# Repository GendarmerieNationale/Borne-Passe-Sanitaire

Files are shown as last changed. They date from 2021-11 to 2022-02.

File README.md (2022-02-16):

# BORNE PASSE SANITAIRE - BPS

Elaborée dans le cadre de la crise COVID, la borne permet de scanner soi-même son passe sanitaire et d’en confirmer la validité, via l’application Tous Anti-Covid Vérif, grâce à un signal sonore. Beaucoup moins coûteux que les produits du marché, cette borne évite de dédier une personne au contrôle des passes sanitaires et répond ainsi à un besoin rendu nécessaire par la crise sanitaire.

Conçue initialement pour les besoins internes de la Gendarmerie (cérémonies, salles de sport, accès des personnes extérieures aux mess…) cette innovation peut être utile à de nombreux acteurs publics et privés (petites collectivités, cinémas...). 

Reposant sur une architecture ANDROID, la borne peut accueillir des applications équivalentes à TAC VERIF dans d'autres pays. Elle peut être également utilisée pour d'autres usages tels que billeterie, contrôle d'accès, etc...

Ce dépôt vous permet de construire une borne passe sanitaire.

## LICENCE

CERN Open Hardware Licence Version 2 - Weakly Reciprocal

## DOCUMENTATION

La documentation est disponible dans le dossier /docs
 - BPS Documentation technique FR.pdf

## IMPRESSION 3D DU BOITIER

### Plans 3D

Les fichiers stl sont disponibles dans le dossier /stl
 - BPS_blocbatterie.stl
 - BPS_fixation.stl
 - BPS_gabarit.stl
 - BPS.stl

### Fichiers gcode pour imprimantes

Les fichiers gcode sont disponibles pour les imprimantes
 - TEVY dans le dossier /gcode/tevy
 - TIZYX dans le dossier /gcode/tizyx

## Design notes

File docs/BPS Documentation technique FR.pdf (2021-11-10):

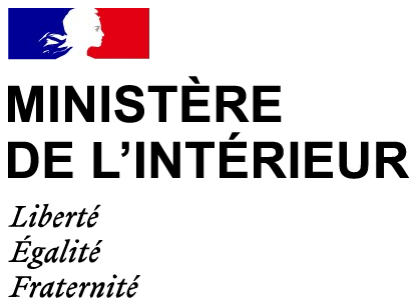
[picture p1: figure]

Gendarmerie nationale

### 20 octobre 2021

N° 67923 GEND/COMSOPGN/SCRTA

D O C U M E N T A T I O N T E C H N I Q U E
B P S – B O R N E P O U R P A S S E S A N I T A I R E

OBJET : Documentation technique de la borne pour passe sanitaire (tutoriel de montage et d’assemblage).

PRESENTATION :
De sa propre initiative, la section CARDIO du SCRTA s’est penchée sur la réalisation d’une borne permettant de vérifier et informer sur la validité d’un passe sanitaire en scannant le QR code depuis la section « carnets » de l’application TousAntiCovid. Le résultat de la validité s’affiche temporairement sur un écran, sans en conserver la donnée.
Ce document a pour objectif de rendre possible la fabrication de la borne « passe sanitaire » par l’ensemble des « makers » gendarmerie.

RÉFÉRENCE(S) :

DESTINATAIRE(S) :
Pour Action :
- DGGN/ST/DPI - Département de la prospective et de l’innovation

A titre de compte rendu :
- COMSOPGN
- SCRTA

Copie :
- Archive CARDIO

Historique des révisions

Numéro de version | Description | Date de modification | Auteur
V1.0 | Création du document | Octobre 2021 | MDC SOPHIE
V1.1 | Modification suite retex terrain DGGN | Octobre 2021 | MDC SOPHIE
V1.2 | Ajout mentions par la DGGN | Octobre 2021 | ST/DPI

A l’exception de l’usage prévu par la notice (et la licence) qui requiert de mentionner la paternité du projet, tous usages de la dénomination « Gendarmerie Nationale » et/ou de son logo institutionnel sont interdits, et ce à quelque titre que ce soit.

Décharge disclaimer
This source is distributed WITHOUT ANY EXPRESS OR IMPLIED WARRANTY, INCLUDING OF MERCHANTABILITY, SATISFACTORY QUALITY AND FITNESS FOR A PARTICULAR PURPOSE. Please see the CERN-OHL-S v2 for applicable conditions.

Conformément à la licence CERN-OHL v2, la mise à disposition de ce document n’implique aucune garantie ni responsabilité pour l’ensemble des usages qui pourraient en être faits.

Ce document est distribué sous la licence CERN Open Hardware Licence Version 2 -Weakly Reciprocal disponible sous le lien ci-contre https://ohwr.org/cern_ohl_w_v2.pdf.

## Table des matières

### 1. PRÉSENTATION DU PRODUIT :

La borne permet de vérifier et informer sur la validité d’un pass sanitaire en scannant le QR code depuis la section « carnets » de l’application TousAntiCovid. Le résultat de la validité s’affiche temporairement sur un écran, sans en conserver la donnée.

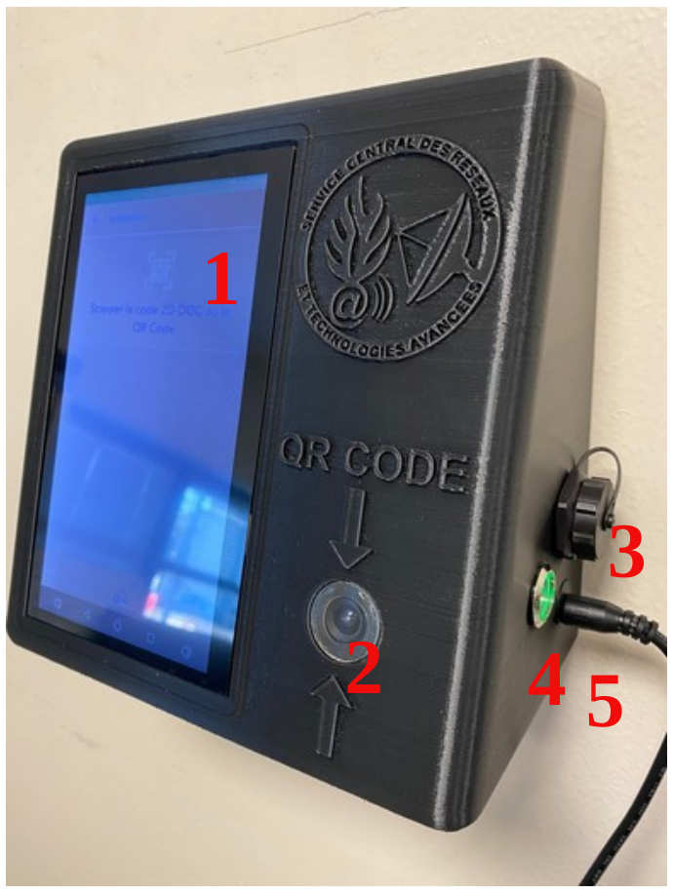
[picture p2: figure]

Le Boîtier est imprimé en 3D (PLA ou ABS). Il est prévu d’être installé au mur à l’aide de trois trous de fixation situés à l’arrière. Un gabarit de perçage est également disponible. Les paramètres d’impression ainsi que l’ensemble des fichiers STL sont disponibles sur le github.

La borne embarque un écran tactile de 7’’ (17cm) monté verticalement afin d’apporter d’avantage d’ergonomie et d’interactivité. (1)
La lecture du QR Code est réalisée par une webcam (2) d’une définition de 1080p, équipée d’une mise au point automatique.
Une fonctionnalité optionnelle est la mise en place d’un système miroir pour faciliter l’ergonomie de la lecture du QR code. Plusieurs solutions techniques sont possibles :
- dispositif électronique sur la caméra et/ou sa connectique ;
- dispositif optique (mise en place d’un miroir à 45°) ;
- dispositif logique (réglage à effectuer sur le pilote de la caméra).
Un port USB (3) est également disponible sur le coté de la borne afin d’y connecter divers périphériques selon le besoin (clavier, souris, clé 4G, etc..). Attention, il n’est pas destiné à la mise en charge (ne pas connecter de source d’alimentation, ex : batterie externe).
La mise en marche/arrêt du système est réalisée à l’aide de l’interrupteur (4) monté sur le coté de la borne (voyant vert → marche).
La mise sous tension secteur est réalisée par un bloc d’alimentation 5V/4A – 5.5x2.5mm - femelle - EU/UK/US (100-240V). Une fiche d’alimentation femelle est également assemblée sur le coté de la borne (5).
L’ensemble des composants électroniques est géré par un micro-ordinateur embarquant un Android 7, 2Go de RAM, et un processeur Quad-Core Rockhip RK3288 (exemple utilisé : ASUS Tinker Board ).

### 2. IMPRESSION 3D DU BOÎTIER :

La borne est conçue et modélisée pour être en majeure partie imprimée en 3D. Elle est décomposée en 4 fichiers STL, ainsi que les fichiers « .gcode » pour imprimante Tizyx EVY, tous disponibles :

Fichiers STL :
Fichiers à ouvrir dans CURA, l’ensemble des paramètres est à renseigner manuellement.
- BPS.stl (fichier principale de la borne).
- BPS_fixation.stl (fichier principale plaque arrière pour fixation).
- BPS_gabarit.stl (fichier optionnel pour faciliter le perçage).
- BPS_blocbatterie.stl (fichier réservé à usage futur pour la fixation d’une batterie).

Fichiers Gcodes (uniquement pour TIZYX EVY) :
Fichier à lancer directement depuis l’imprimante, il contient l’ensemble des paramètres d’impression. Cette opération est recommandée par la section CARDIO.
- TEVY_BPS.gcode
- TEVY_BPS_fixation.gcode (fichier principale plaque arrière
pour fixation).
- TEVY_BPS_gabarit.gcode (fichier optionnel pour faciliter le perçage).
- TEVY_BPS_Blocbatterie.gcode (fichier réservé usage futur pour la fixation d’une batterie).

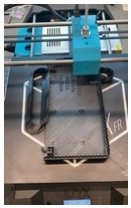
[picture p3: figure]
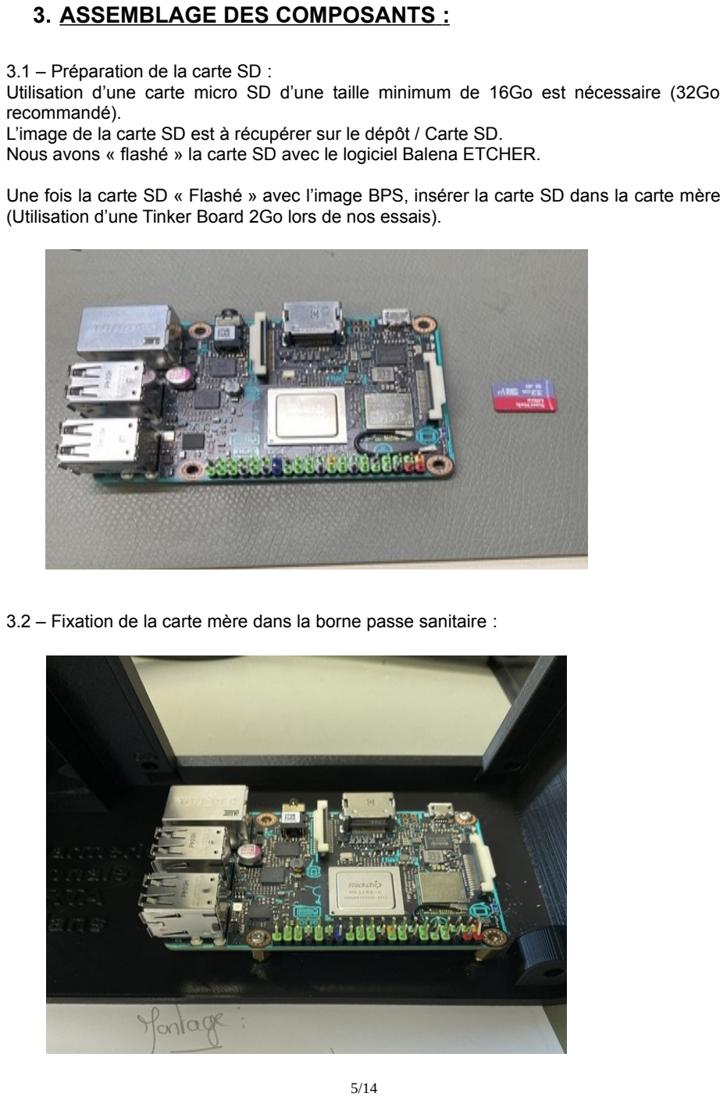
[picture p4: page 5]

### 3. ASSEMBLAGE DES COMPOSANTS :

3.1 – Préparation de la carte SD :
Utilisation d’une carte micro SD d’une taille minimum de 16Go est nécessaire (32Go recommandé).
L’image de la carte SD est à récupérer sur le dépôt / Carte SD.
Nous avons « flashé » la carte SD avec le logiciel Balena ETCHER.

Une fois la carte SD « Flashé » avec l’image BPS, insérer la carte SD dans la carte mère (Utilisation d’une Tinker Board 2Go lors de nos essais).

3.2 – Fixation de la carte mère dans la borne passe sanitaire :

Fixation des inserts (x4)
pour la carte mère

3.3 – Insérer les connectiques sur la carte mère :

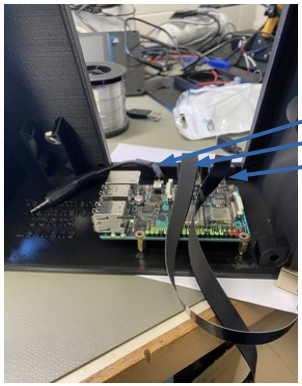
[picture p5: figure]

3. 4 – Fixation de l’écran tactile :

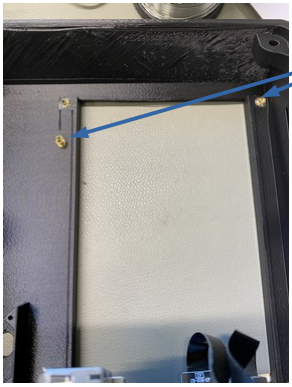
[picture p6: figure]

Attention : Avant la pose de l’écran, connecter les connectiques HDMI et USB.

Cordon jack 3.5 audio
Cordon HDMI coudé
Cordon USB coudé

Pose des inserts (x4)

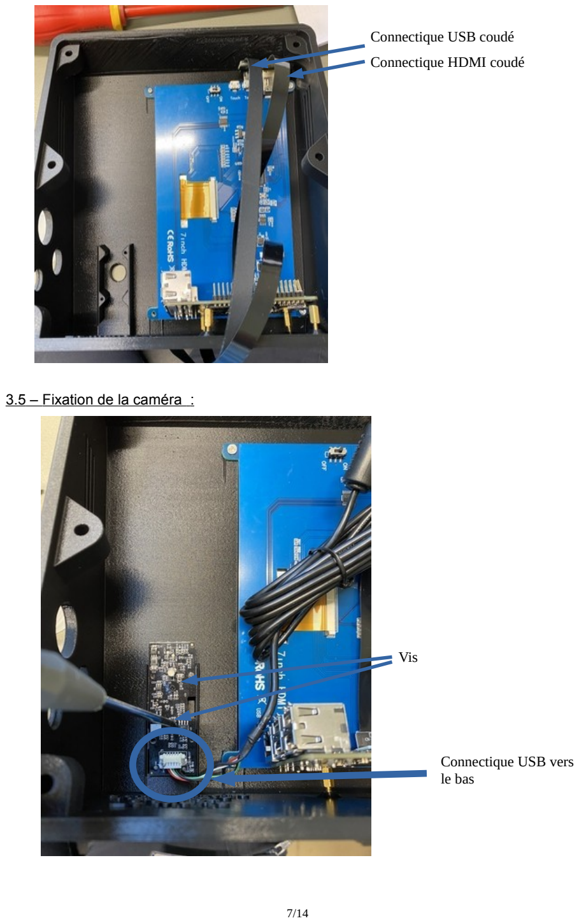
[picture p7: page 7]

3. 5 – Fixation de la caméra :

Connectique USB coudé
Connectique HDMI coudé

Connectique USB vers
le bas

Vis

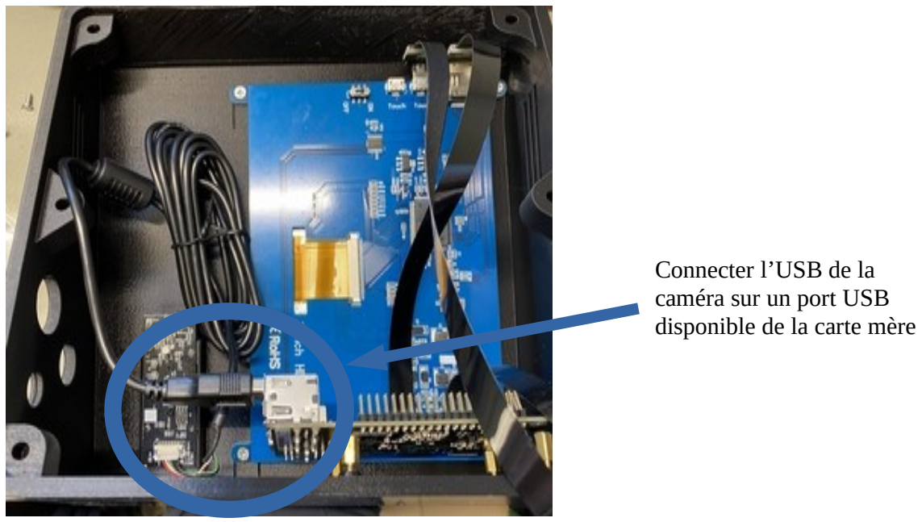
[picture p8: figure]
Connecter l’USB de la caméra sur un port USB disponible de la carte mère

3. 6 – Insertion des connectiques externes :

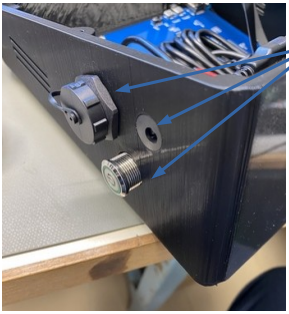
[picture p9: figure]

Insérer les connectiques :
- USB
- Alimentation
- Interrupteur

3. 7 – Connexion des connectiques et éléments internes :

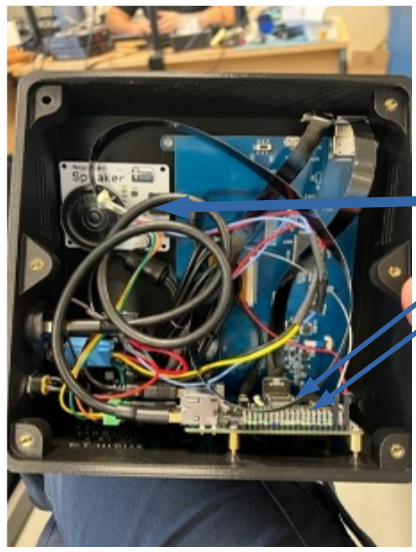
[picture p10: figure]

Fixation du Speaker (double face) : Jack 3.5
5V sur la carte mère
GND sur la carte mère

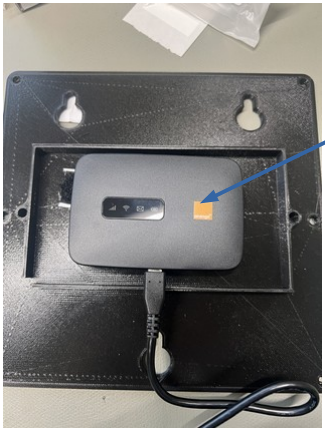
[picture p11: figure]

Fixation du routeur 4G mobile (option): Par velcro

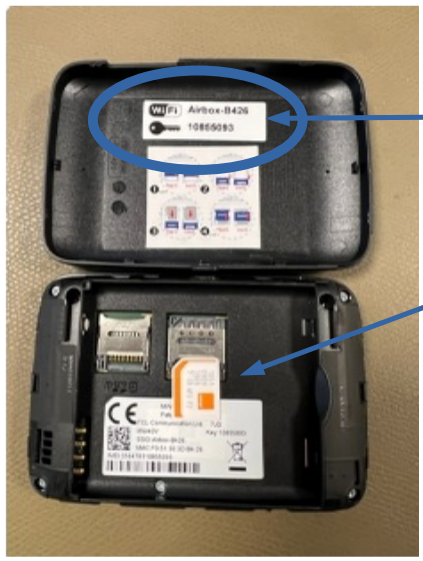
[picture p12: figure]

### 4. PREMIÈRE MISE EN MARCHE

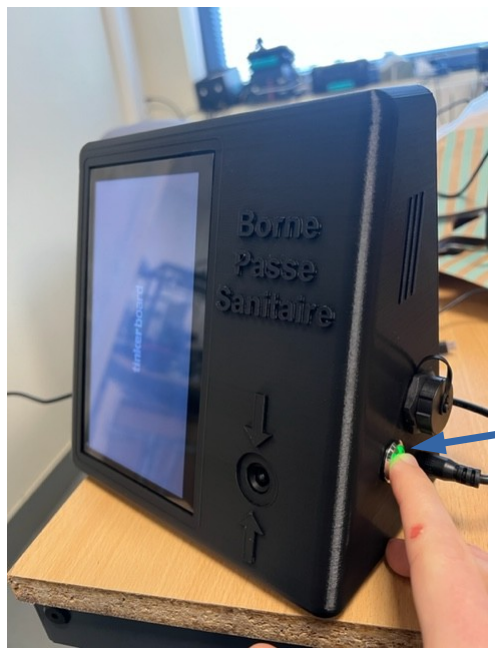
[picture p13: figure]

Après avoir connecté le bloc d’alimentation au secteur, presser l’interrupteur de mise en marche. Voyant vert = mise en marche

Noter le code Wifi et le SSID

Insérer la carte SIM à l’intérieur du routeur. S’assurer que le code PIN soit « 0000 »
NE PAS OUBLIER D’INSERER LA BATTERIE DU ROUTEUR 4G

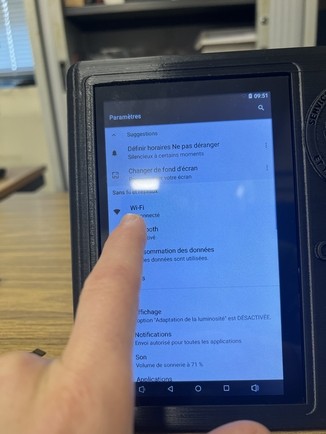
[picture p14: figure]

Se rendre dans Paramètres −> Wifi

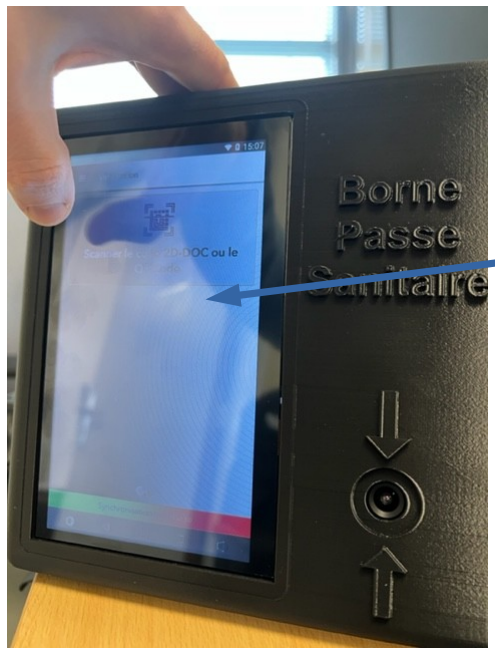
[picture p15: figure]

Le système démarre automatiquement sur l’application « TAC VERIF ». Avant d’appuyer sur « Scanner », il est nécessaire de paramétrer le réseau sans fil WIFI, afin de mettre à jour les bases et effectuer les mises à jour de TAC Vérif.

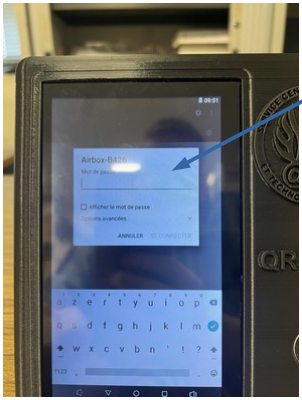
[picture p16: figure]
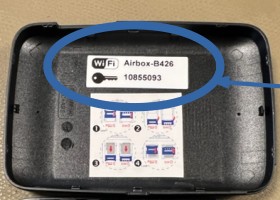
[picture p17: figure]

Une fois connecté à internet, l’heure de la borne se synchronise, l’application TAC VERIF demande une mise à jour. NE PAS APPUYER DANS L’ENCADR E ROUGE :

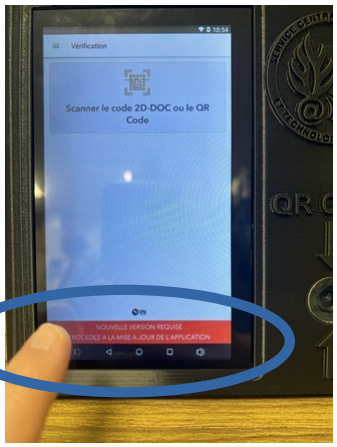
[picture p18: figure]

En effet, dans l’attente des RETEX terrain, nous n’avons pas associé de compte Google Play à la BPS. Les mises à jour sont donc à réaliser manuellement (APK).
Deux solutions pour la mise à jour de l’application :
1 – Soit par internet depuis la BPS ;
2 – Soit en téléchargeant l’APK depuis un poste fixe et utiliser une clé USB pour le transfert (à connecter sur le coté de la borne).

Choisir son réseau wifi ou alors (si option 4G), se connecter au routeur 4G

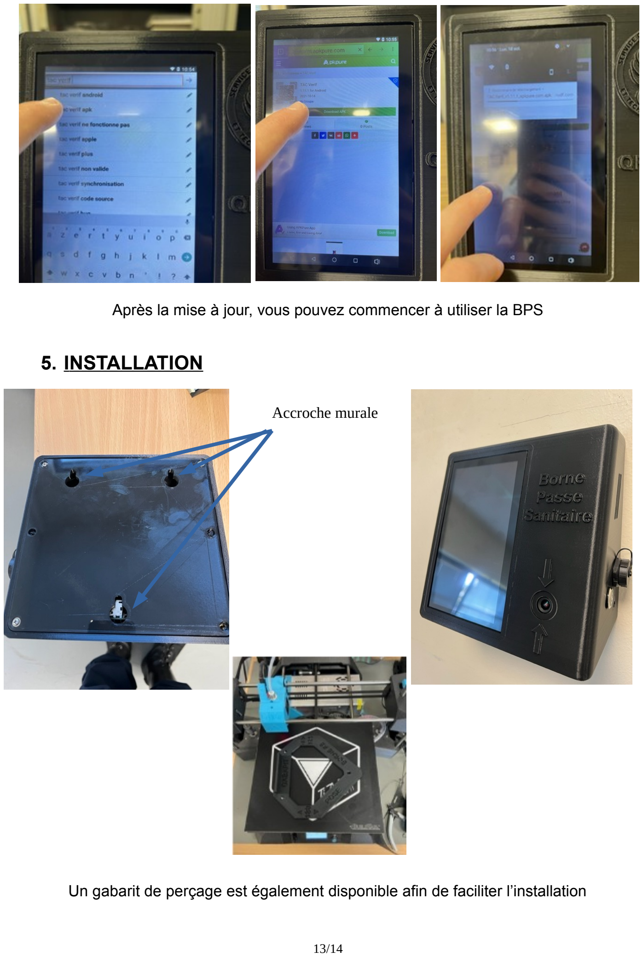
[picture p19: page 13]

Après la mise à jour, vous pouvez commencer à utiliser la BPS

### 5. I NSTALLATION

Un gabarit de perçage est également disponible afin de faciliter l’installation

Accroche murale

### 6. COMPOSANTS :

Désignation | Quantité
Micro-ordinateur embarquant un Android 7, 2Go de RAM, et un processeur Quad-Core Rockhip RK3288 (exemple utilisé : ASUS Tinker Board ) | 1
Carte micro SD – 16 Go minimum | 1
Câble HDMI coudé vers HDMI coudé en nappe | 1
Câble micro USB coudé vers micro USB coudé | 2
Interrupteur 5-12V – 5A vert pour montage circulaire panneau | 1
Bloc d’alimentation 5V/4A – 5.5x2.5mm - femelle - EU/UK/US (100-240V). | 1
Fiche d’alimentation femelle pour 5.5x2.5mm pour montage circulaire panneau | 1
Fiche d’alimentation USB étanche vers USB pour montage panneau circulaire | 1
Webcam 1080p USB démontable avec mise au point automatique | 1
Ecran tactile 7’’ pour micro ordinateur (raspberry, etc..) | 1
Haut-parleur 2W/5W compatible micro-ordinateur (raspberry, etc ..) | 1
Lot visserie pour micro-ordinateur | 1

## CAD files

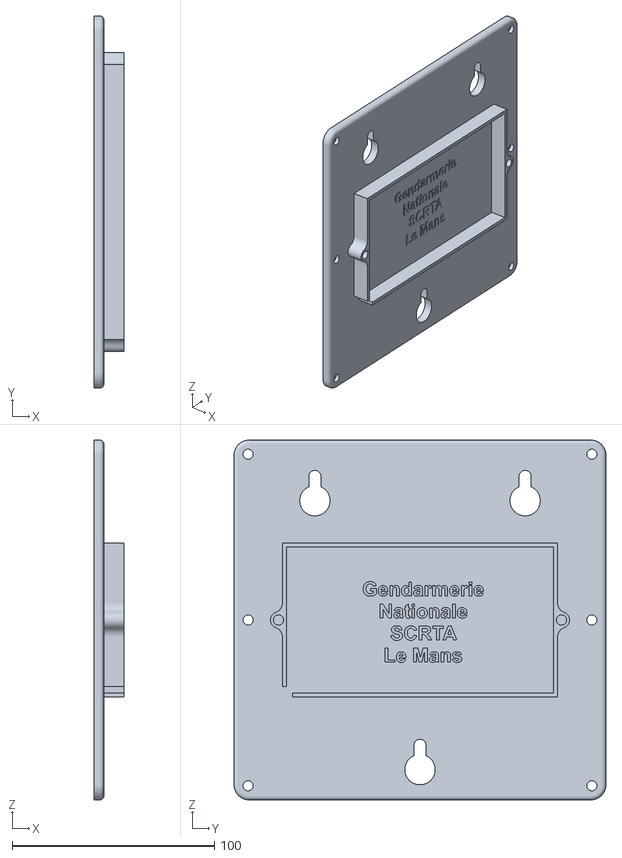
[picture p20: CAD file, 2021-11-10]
stl/BPS_fixation.stl
15.0 x 184.0 x 178.0

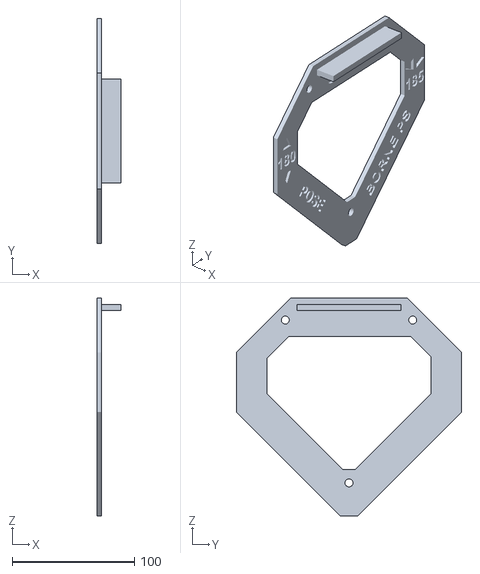
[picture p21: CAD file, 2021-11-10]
stl/BPS_gabarit.stl
20.0 x 184.0 x 178.0

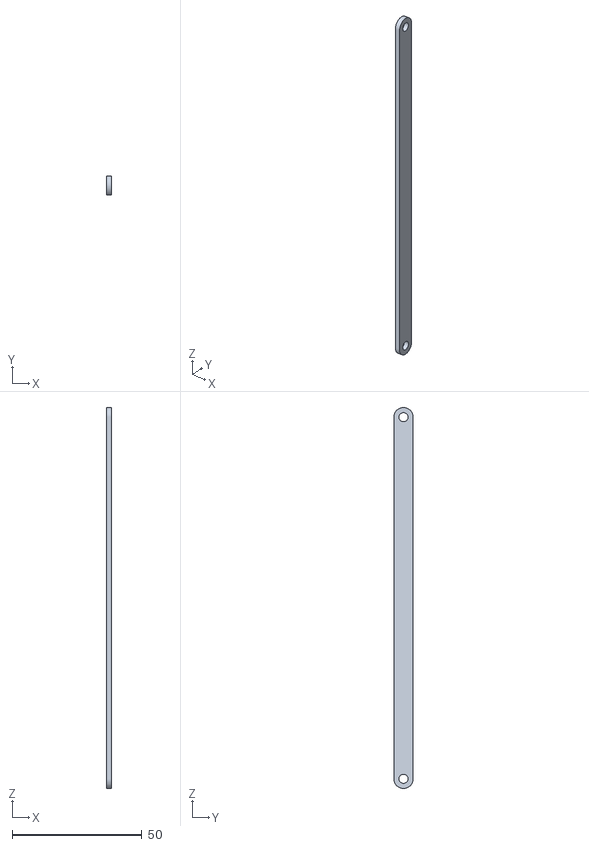
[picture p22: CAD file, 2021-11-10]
stl/BPS_blocbatterie.stl
2.00 x 7.50 x 147.0

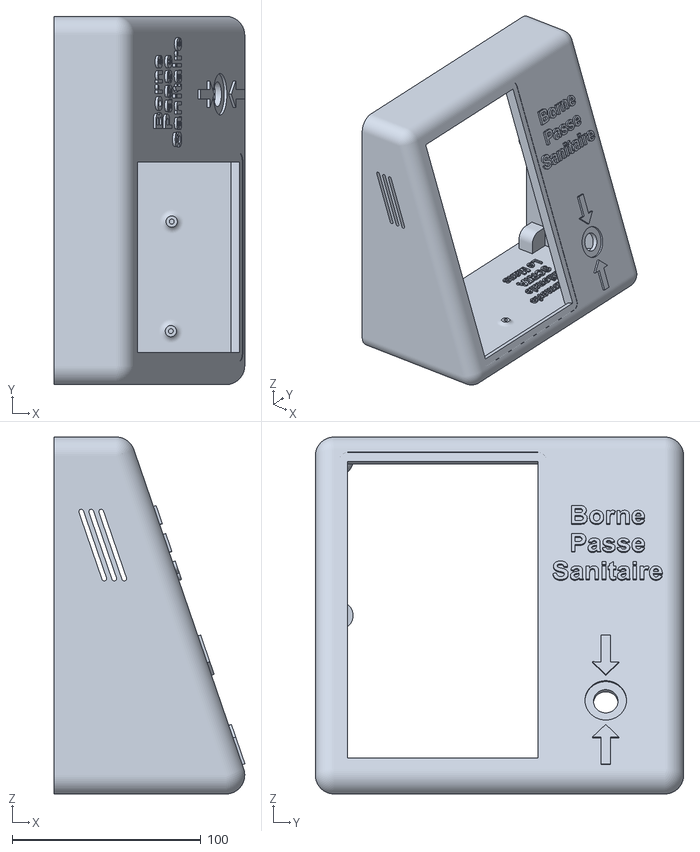
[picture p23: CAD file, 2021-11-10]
stl/BPS.stl
101.1 x 195.0 x 189.0

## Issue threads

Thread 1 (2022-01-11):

Suggestion d'utilisation de la plateforme APKPure

TeddyBear06, 2022-01-11:
Bonjour,

Tout d'abord, merci pour le partage de ce travail sur cette borne.

Je souhaite attirer votre attention sur le potentiel problème de sécurité que lève la suggestion de l'utilisation de la plateforme "APKPure" pour récupérer le fichier APK de "TAC Verif"[^0].

En effet, l'histoire nous à démontré que, même avec la meilleure volonté des responsables de la plateforme "APKPure", elle n'est pas à l'abri d'un cheval de Troie.

En avril 2021, Kaspersky a découvert un adware dissimulé dans l'application officielle "APKPure"[^1].

De plus, à l'instant où je vous parle, la version de "TAC Verif" disponible sur "APKPure" est la 2.3.1 or, la dernière version disponible sur le "Play Store" (magasin d'applications officiel Google) est la 2.3.2.

Je ne peux donc pas vérifier l'empreinte numérique de la version proposée par "APKPure" et celle disponible actuellement dans le "Play Store" (elle seraient probablement identiques, mais peut être pas).

Certes, il n'y a probablement pas de grands changements entre ces 2 versions mineures[^2], mais un retard de version est potentiellement problématique pour de nombreuses raisons (failles, bugs, etc...).

Au vu du besoin, il serait d'utilité publique que "IN Groupe" mette à disposition un APK téléchargeable directement (avec sa signature SHA1/whatever, par exemple pour vérifier après téléchargement que le fichier APK n'a pas été altéré) comme le fait l'application "Signal"[^3].

L'INRIA semble publier les dernières versions de TAC Verif[^4] (merci à eux) mais, sauf erreur de ma part, sans release des APK par version.

Je suggère de retirer les captures d'écrans "APKPure" de la documentation technique car, selon moi, elles ne constituent pas une alternative fiable au téléchargement de l'APK "TAC Verif".

Un APK peut être considéré comme "fiable"[^5] uniquement si il est récupéré auprès de l'éditeur (en l'occurrence "IN Groupe") ou d'un tiers de confiance identifié (Play Store ou autre store suivant le système concerné).

Bien à vous,

[^0]: Captures d'écran en haut de la page 13 de la [documentation technique de la Borne-Passe-Sanitaire](https://github.com/GendarmerieNationale/Borne-Passe-Sanitaire/blob/main/docs/BPS%20Documentation%20technique%20FR.pdf)
[^1]: [Communiqué de presse](https://www.kaspersky.fr/blog/infected-apkpure/16732/) et [documentation technique](https://securelist.com/apkpure-android-app-store-infected/101845/)
[^2]: Le changelog de la 2.3.2 indique, je cite : "Cette version 2.3.2 pour Android corrige quelques bugs mineurs."
[^3]: https://signal.org/android/apk/
[^4]: https://gitlab.inria.fr/tousanticovid-verif/tousanticovid-verif-android
[^5]: Fiable au sens "le moins d'intermédiaires possible et dont l'authenticité peut être vérifié à l'aide d'une empreinte numérique"
